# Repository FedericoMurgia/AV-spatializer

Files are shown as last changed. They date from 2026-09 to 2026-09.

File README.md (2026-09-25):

# AV Spatializer

**A five-control audiovisual controller by Studio Federico Murgia (beta)**

A joystick, a potentiometer and two sliders, with an 8×8 WS2812B LED matrix
under a frosted diffuser that shows what the controls are doing as light:
position, block size, brightness, colour and strobe. Built on an ESP32, in a
3D-printed enclosure.

<div align="center">

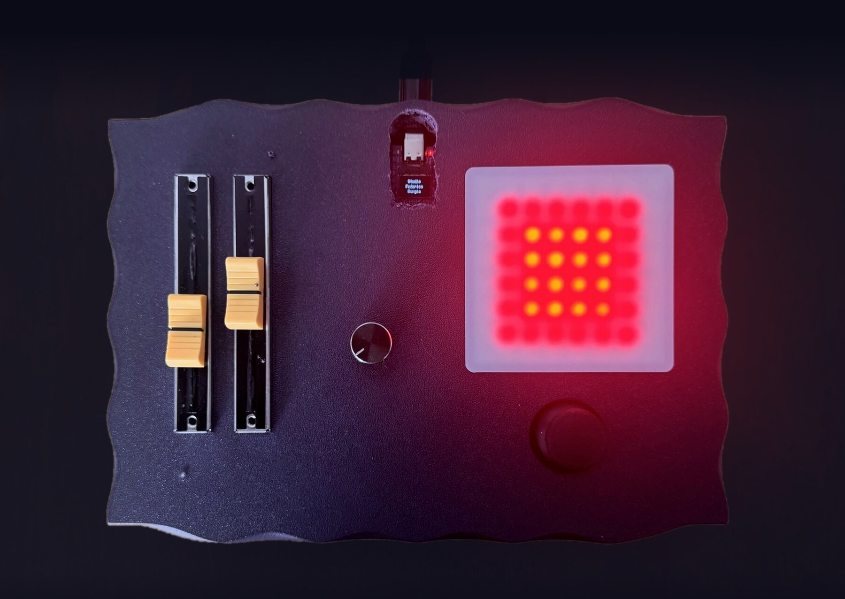
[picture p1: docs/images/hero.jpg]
AV Spatializer, top view


</div>

---

> [!WARNING]
> **Photosensitive epilepsy.** Two of the eight colour modes strobe the matrix
> at 1–20 Hz. Do not build or operate it if you are sensitive to
> photosensitive epilepsy.

> [!NOTE]
> **This is the beta.** It works, and it will change before a small limited
> edition. Two firmware variants exist and they
> do not do the same thing yet; see [Firmware](#firmware).

## What this is

The controller was first built as a spatializer: the joystick moves a sound
source around the room in 4DSOUND, a slider sets its size, and the LED matrix
mirrors where the source sits and how large it is.

<table>
<tr>
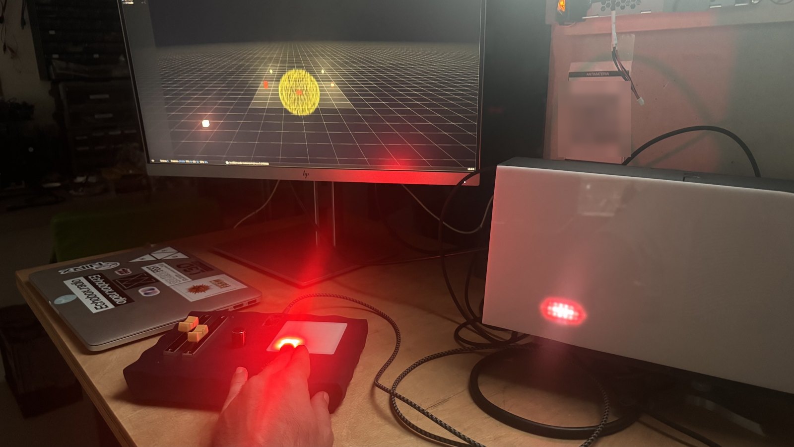
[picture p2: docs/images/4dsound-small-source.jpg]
Source made smaller and moved to the bottom left in 4DSOUND
<td width="50%"></td>
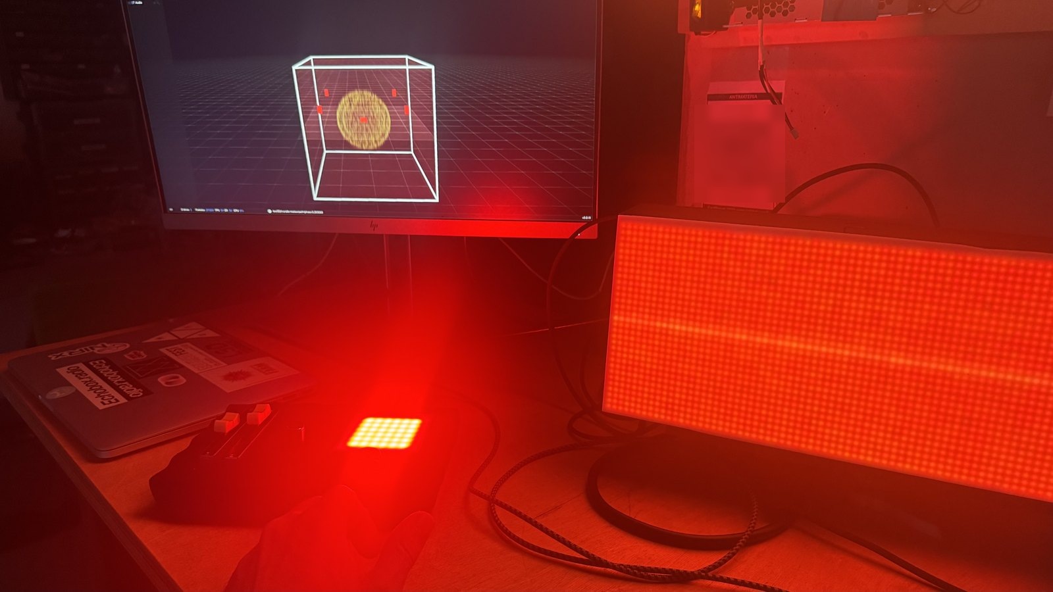
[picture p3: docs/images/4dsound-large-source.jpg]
The same source enlarged and left in the centre
<td width="50%"></td>
</tr>
<tr>
<td align="center"><em>The source made smaller and moved to the bottom left.</em></td>
<td align="center"><em>The same source enlarged and left in the centre.</em></td>
</tr>
</table>

It was then configured and performed for **Hotaru Open** with John Bringwolves
at Castello di Rivoli (May 2026, ADRenaline programme), where the joystick
positioned an audiovisual effect across a 10.1 speaker system and 16 lights.

<div align="center">
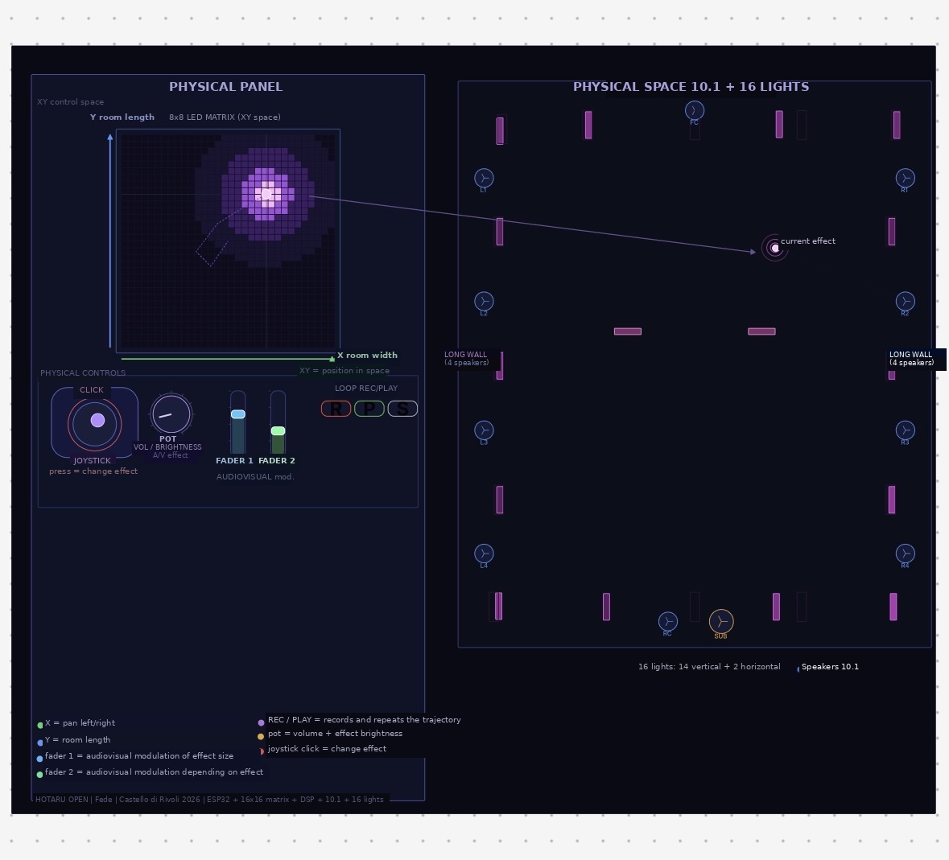
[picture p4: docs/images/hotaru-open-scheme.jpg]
Control scheme built for Hotaru Open


<em>The control scheme built and performed for Hotaru Open.</em>
</div>

Outside that setup it is a general-purpose controller: five continuous values
and a mode switch, readable by anything that takes MIDI or serial.

## Specifications

| | |
|---|---|
| **Controls** | 2-axis analog joystick with push, 1 rotary potentiometer, 2 slide potentiometers |
| **Display** | 8×8 WS2812B matrix (64 px) under a frosted diffuser |
| **Beta unit (pictured)** | ESP32-C3 board with onboard 0.42" 72×40 SSD1306 OLED, USB serial output |
| **BLE MIDI variant** | Classic ESP32, no screen, BLE MIDI Control Change output |
| **Frame rate** | 50 fps matrix update |
| **Enclosure** | 3D printed, two parts: top 217 × 157 × 26 mm, bottom 200 × 140 × 13.3 mm |

## Contents

| Path | What |
|---|---|
| [`docs/WIRING.md`](docs/WIRING.md) | Pin tables for both boards, matrix layout, power notes |
| [`docs/SERIAL.md`](docs/SERIAL.md) | The tagged serial stream from the ESP32-C3 firmware |
| [`docs/MIDI.md`](docs/MIDI.md) | The BLE MIDI map from the ESP32 firmware |
| [`docs/AV_Spatializer.pdf`](docs/AV_Spatializer.pdf) | Two-page overview sheet |
| [`firmware/`](firmware/) | Both firmware variants as PlatformIO projects |
| [`examples/`](examples/) | A minimal Python reader for the serial stream |
| [`hardware/enclosure/`](hardware/enclosure/) | Printable enclosure STLs |

## Controls

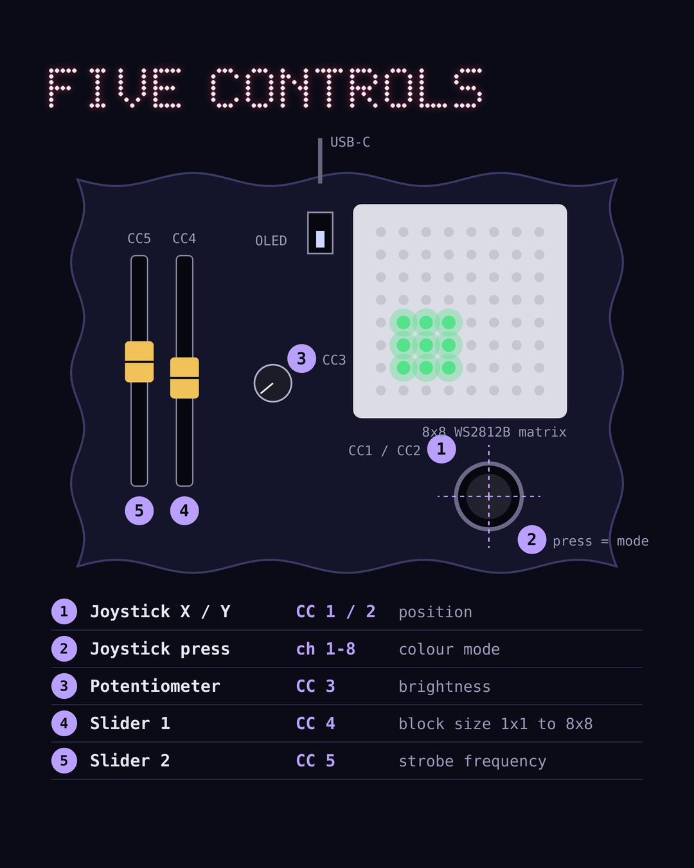
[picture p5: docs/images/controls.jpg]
The five controls


| # | Control | On the matrix | BLE MIDI variant |
|:-:|---|---|---|
| 1 | Joystick X / Y | Position of the lit block | CC 1 / CC 2 |
| 2 | Joystick press | Next colour mode (8 modes) | Channel = mode (1–7) |
| 3 | Potentiometer | Brightness | CC 3 |
| 4 | Slider 1 | Block size, 1×1 to 8×8 | CC 4 |
| 5 | Slider 2 | Strobe frequency, 1–20 Hz | CC 5 |

Odd block sizes above 1 are drawn as the next even size with a dimmed outer
ring (about 20% brightness).

The joystick centre is **calibrated at power-up** from 32 samples. Leave the
joystick untouched while the unit boots, or the centre will be offset for the
whole session.

### Colour modes

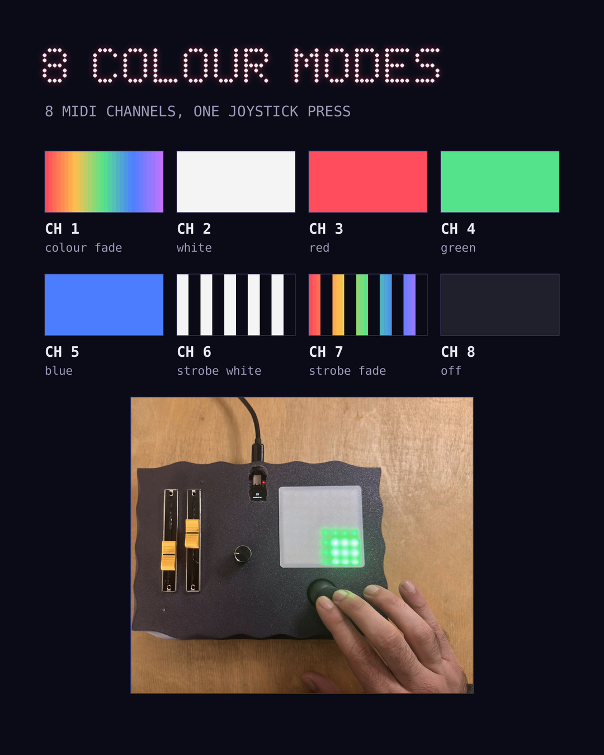
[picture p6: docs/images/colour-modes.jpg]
Eight colour modes


| Mode | Colour | MIDI channel (BLE variant) |
|:----:|---|:---:|
| 0 | Colour fade (hue cycles every frame) | 1 |
| 1 | White | 2 |
| 2 | Red | 3 |
| 3 | Green | 4 |
| 4 | Blue | 5 |
| 5 | Strobe white | 6 |
| 6 | Strobe fade | 7 |
| 7 | Off, matrix dark, no output | none |

## Build

### Bill of materials

| # | Component | Spec / Notes | Qty |
|---|---|---|:---:|
| 1 | Microcontroller | ESP32-C3 board with onboard 0.42" 72×40 SSD1306 OLED (C3 beta), **or** classic ESP32 dev board (BLE MIDI variant) | 1 |
| 2 | LED matrix | WS2812B 8×8 panel (64 LEDs) | 1 |
| 3 | OLED display | C3 beta only, onboard on the board above. The BLE MIDI variant has no screen | (1) |
| 4 | Analog joystick | KY-023 or equivalent (X/Y + button) | 1 |
| 5 | Potentiometer | 10 kΩ, panel-mount rotary | 1 |
| 6 | Slider potentiometer | 10 kΩ linear, panel-mount | 2 |
| 7 | Resistor | 330–470 Ω (WS2812 data line) | 1 |
| 8 | Capacitor | 100–1000 µF / 6.3 V (power decoupling on LED matrix VCC) | 1 |
| 9 | USB cable | Matching the board's USB connector | 1 |
| 10 | Enclosure | 3D printed, STLs in [`hardware/enclosure/`](hardware/enclosure/) | 1 |
| 11 | Wiring | 22–26 AWG hookup wire, various | — |
| 12 | PCB or perfboard | For mounting and connecting components | 1 |
| 13 | Diffuser | Frosted / opal acrylic over the matrix | 1 |

### Wiring

Pin tables for both boards: **[`docs/WIRING.md`](docs/WIRING.md)**.

### Enclosure

Two printed parts in [`hardware/enclosure/`](hardware/enclosure/).

<table>
<tr>
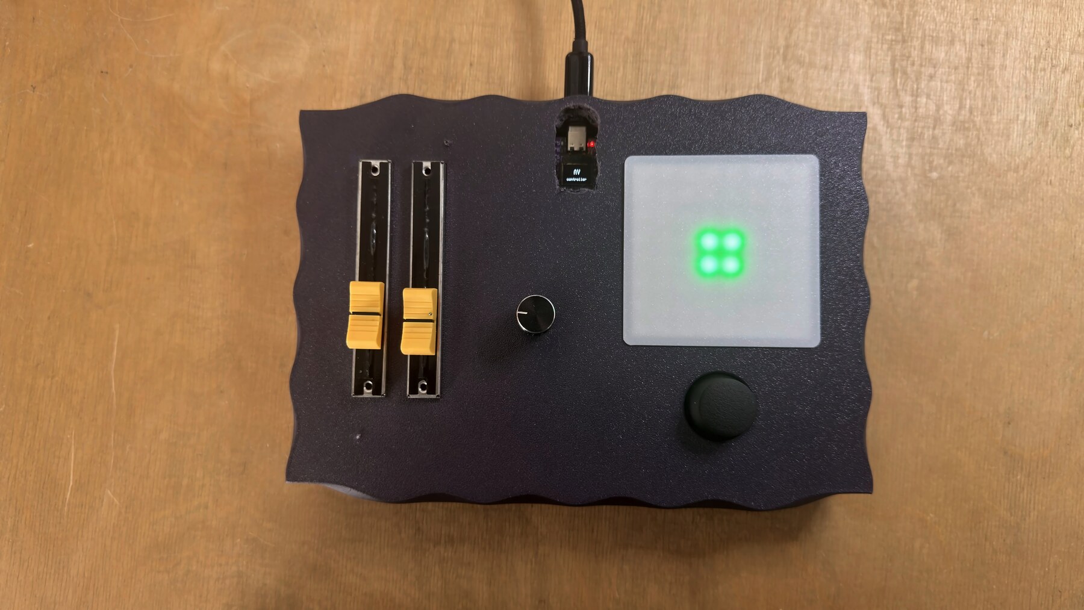
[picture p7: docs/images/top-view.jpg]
Top view in daylight
<td width="50%"></td>
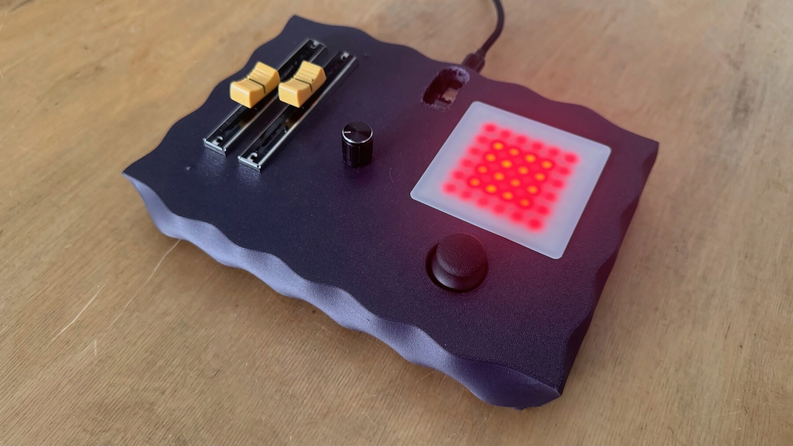
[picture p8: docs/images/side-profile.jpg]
Side profile of the enclosure
<td width="50%"></td>
</tr>
</table>

## Firmware

Two PlatformIO projects in [`firmware/`](firmware/). They share the same
control logic (joystick calibration, block drawing, colour modes, strobe) and
differ in output:

| | [`esp32c3-oled`](firmware/esp32c3-oled/) | [`esp32-blemidi`](firmware/esp32-blemidi/) |
|---|---|---|
| Board | ESP32-C3 with 0.42" OLED (the pictured beta) | Classic ESP32 |
| Output | USB serial, tagged stream, 50 Hz | BLE MIDI CC, ≤10 Hz per change |
| Screen | Shows brightness, size, strobe Hz, X/Y | None |
| Brightness | Pot sets 0–255 directly | Pot scaled per mode and block size, FastLED power cap |

**BLE MIDI is not yet in the ESP32-C3 firmware.** The C3 has Bluetooth LE, so
merging the two is the next step for the beta.

## Using it

<table>
<tr>
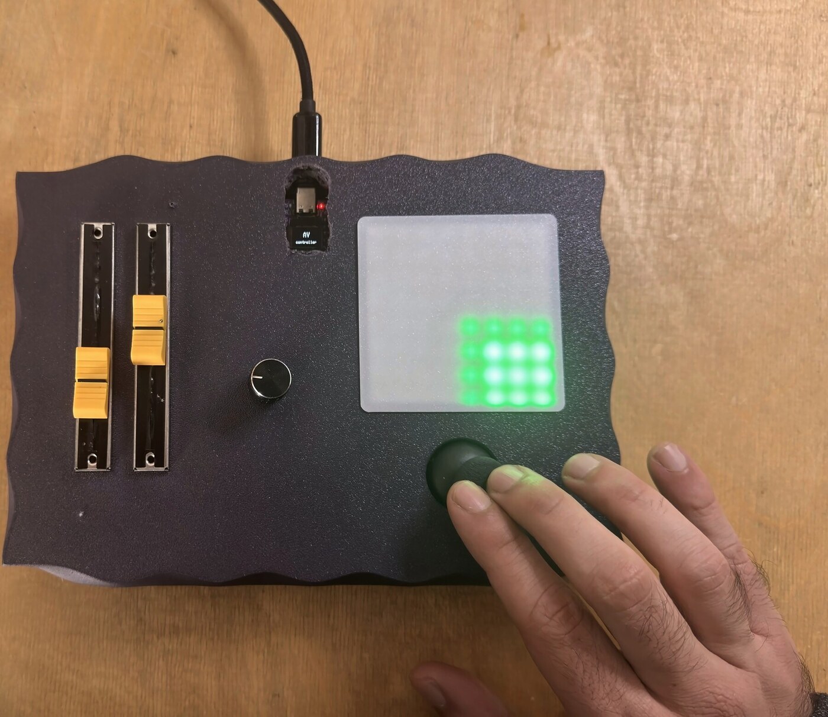
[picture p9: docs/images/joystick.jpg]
Joystick moving the lit block
<td width="50%"></td>
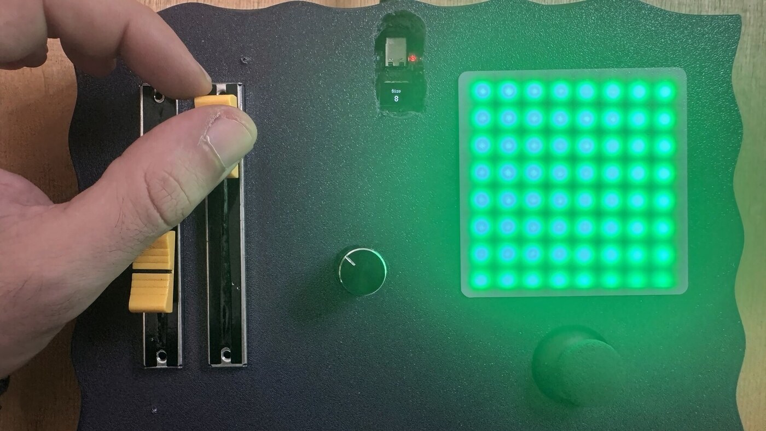
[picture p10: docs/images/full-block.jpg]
Block at full 8x8 size
<td width="50%"></td>
</tr>
<tr>
<td align="center"><em>Joystick moving the block.</em></td>
<td align="center"><em>Block at full 8×8 size.</em></td>
</tr>
</table>

- **BLE MIDI variant:** pair "AV Controller" as a Bluetooth MIDI device
  (macOS: Audio MIDI Setup → MIDI Studio → Bluetooth), then MIDI-learn the five
  CCs in Ableton Live, TouchDesigner, Max, Pure Data or any MIDI host.
- **ESP32-C3 beta:** open the USB serial port at 115200 baud and parse the
  stream; [`docs/SERIAL.md`](docs/SERIAL.md) has the format and
  [`examples/serial_reader.py`](examples/serial_reader.py) a working reader.

## Try one

Build your own from this repo, or get in touch: depending on the project, a beta
unit can be lent or sold at a small price. Whatever you find while building,
testing or breaking it, open an issue; the feedback goes into the limited
edition.

## License

- **Firmware and example code:** MIT, see [`LICENSE`](LICENSE)
- **Documentation, images and enclosure design:** CC BY-SA 4.0

## Credits

Built on [FastLED](https://github.com/FastLED/FastLED),
[U8g2](https://github.com/olikraus/u8g2) and
[NimBLE-Arduino](https://github.com/h2zero/NimBLE-Arduino).

AV Spatializer is a project by **Studio Federico Murgia**.

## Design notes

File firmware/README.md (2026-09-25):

# Firmware

Two PlatformIO projects. Open either folder in VS Code with the PlatformIO
extension, or build from the command line:

```sh
cd firmware/esp32c3-oled      # or firmware/esp32-blemidi
pio run -t upload
pio device monitor            # 115200 baud
```

| Folder | Board | Output | Libraries |
|---|---|---|---|
| [`esp32c3-oled/`](esp32c3-oled/) | ESP32-C3 with onboard 0.42" 72×40 SSD1306 | USB serial, see [`../docs/SERIAL.md`](../docs/SERIAL.md) | FastLED, U8g2 |
| [`esp32-blemidi/`](esp32-blemidi/) | Classic ESP32 | BLE MIDI, see [`../docs/MIDI.md`](../docs/MIDI.md) | FastLED, NimBLE-Arduino 1.x |

The `platformio.ini` files are reference configs. The C3 build enables USB CDC
on boot so `Serial` appears on the native USB port; if your C3 board has a
separate USB-UART chip, remove those two flags.

## Settings worth knowing

All at the top of each `main.cpp`:

| Constant | Value | Effect |
|---|---|---|
| `DEADZONE` | 250 | ADC counts around the joystick centre that read as centre |
| `AXIS_HALF_RANGE` | 1500 | Joystick travel mapped to the full grid, kept under the ADC limit so full deflection reaches the edge |
| `STROBE_HZ_MIN` / `MAX` | 1 / 20 | Strobe range on slider 2 |
| `FRAME_INTERVAL_MS` | 20 | 50 fps |
| `DEBOUNCE_MS` | 50 | Joystick push debounce |

## Roadmap

- Bring BLE MIDI into the ESP32-C3 firmware, so the pictured unit sends MIDI
  and keeps its screen.

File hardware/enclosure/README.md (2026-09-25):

# Enclosure

Two 3D-printed parts. Sizes are the STL bounding boxes.

| File | Bounding size | Role |
|---|---|---|
| `av-spatializer-top.stl` | 217 × 157 × 26 mm | Top shell (was `AVmidicontroller.stl`) |
| `av-spatializer-bottom.stl` | 200 × 140 × 13.3 mm | Bottom (was `AVcontrollerbottom.stl`) |

The diffuser over the LED matrix is not printed: use frosted or opal acrylic
cut to the matrix window.

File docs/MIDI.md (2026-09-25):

# BLE MIDI (ESP32 firmware)

The `esp32-blemidi` firmware advertises as **"AV Controller"** using the
standard BLE MIDI service (`03B80E5A-EDE8-4B33-A751-6CE34EC4C700`). Pair it as a
Bluetooth MIDI device on the host; on macOS through Audio MIDI Setup → MIDI
Studio → Bluetooth.

## Map

| Control | CC | Value |
|---|:--:|---|
| Joystick X | 1 | Grid position 0–8 scaled to 0–127 |
| Joystick Y | 2 | Grid position 0–8 scaled to 0–127 |
| Potentiometer | 3 | 0–127 |
| Slider 1 | 4 | 0–127 (inverted in firmware to match block size) |
| Slider 2 | 5 | 0–127 (inverted in firmware to match strobe rate) |

**Channel = colour mode + 1.** A joystick press moves to the next mode, and all
five CCs move to the next channel with it. On a channel change all five CCs are
sent at once, so the host receives the current state on the new channel.

## Timing

- CCs are checked every **100 ms** and only sent when they change: X and Y on
  any change, the potentiometer and sliders when they move by more than 1.
- Each CC is sent as its own BLE notification, the most widely compatible form.
- Joystick X/Y are quantised to the 9 grid positions, so they step
  (0, 15, 31, 47 … 127) rather than sweep.

## Known behaviour

- **Mode 7 is off:** the matrix goes dark and no MIDI is sent. Channels 1–7
  carry the CCs.
- Joystick centre is calibrated at power-up. Do not touch the joystick while
  the board boots.

## Library

Written against **NimBLE-Arduino 1.x**. Version 2.x changed the server callback
signatures (`onConnect`, `onDisconnect`), so the callbacks here will not compile
against 2.x without updating them. `platformio.ini` pins 1.x.

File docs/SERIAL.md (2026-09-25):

# Serial stream (ESP32-C3 firmware)

USB serial, **115200 baud**. After boot the board prints `ready`, then one line
per frame (50 Hz):

```
sx-2051-sy-2040-x-4-y-4-p-3120-s1-812-s2-3990-m-0
```

| Tag | Value | Range |
|-----|---|---|
| `sx` | Joystick X, smoothed raw ADC | 0–4095 |
| `sy` | Joystick Y, smoothed raw ADC | 0–4095 |
| `x` | Joystick X as grid position | 0–8, 4 = centre |
| `y` | Joystick Y as grid position | 0–8, 4 = centre |
| `p` | Potentiometer, smoothed raw ADC | 0–4095 |
| `s1` | Slider 1, smoothed raw ADC | 0–4095 |
| `s2` | Slider 2, smoothed raw ADC | 0–4095 |
| `m` | Colour mode | 0–7 |

Notes read from the firmware:

- `sx`/`sy` are exponentially smoothed (α 0.4); `p`, `s1`, `s2` use α 0.8.
- `x`/`y` include a dead zone of ±250 ADC counts around the centre calibrated
  at boot, so small movements report 4.
- `s1` and `s2` are raw. The firmware inverts them internally: block size is
  `map(s1, 0, 4095, 8, 1)` and strobe is `1 + (4095 - s2) / 4095 × 19` Hz.
- In mode 7 (off) the matrix is blanked and **no lines are sent** until the
  mode changes.

A minimal reader is in [`../examples/serial_reader.py`](../examples/serial_reader.py).

## OLED

The onboard 72×40 screen shows whichever control moved last:

| Moved | Screen |
|---|---|
| Potentiometer | `Bright` and 0–100 % |
| Slider 1 | `Size` and 1–8 |
| Slider 2 | `Strobe` and Hz |
| Joystick | `X  Y` and offset from centre, −4 to +4 |

In the two strobe modes it shows `STROBE` once and then stops redrawing. After
two seconds without activity it alternates between two idle pages.

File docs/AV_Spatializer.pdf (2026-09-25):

ESP32-C3 audiovisual MIDI controller, five controls, 8x8 LED matrix | BETA

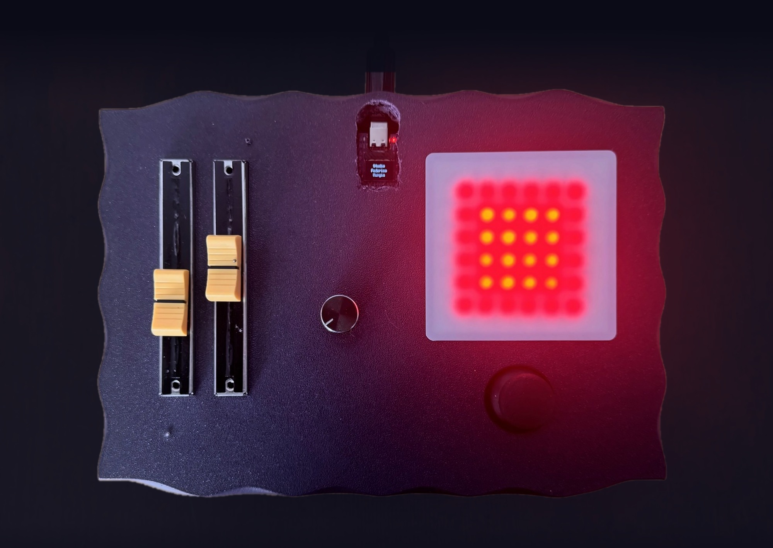
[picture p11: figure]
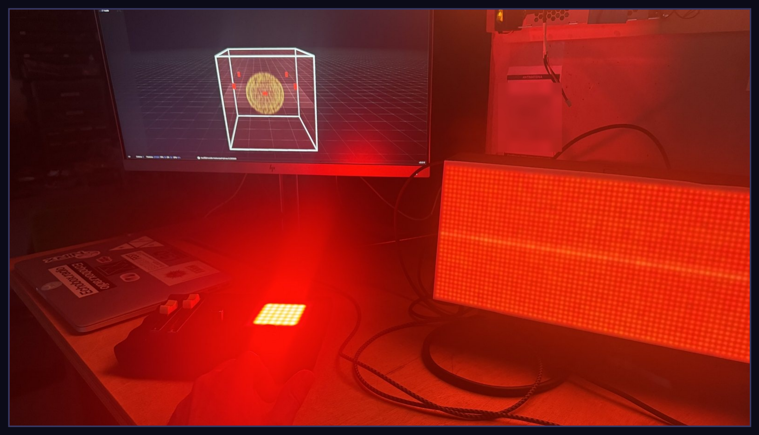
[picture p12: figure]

Studio Federico Murgia, Amsterdam | 1 / 2

Top view: sliders, potentiometer, 8x8 LED matrix under a frosted diffuser, joystick, OLED display and USB-C.

WHAT IT IS
A hand-built controller with five controls: a two-axis joystick with click, a potentiometer and two sliders. An 8x8 WS2812B LED matrix under a frosted diffuser shows what the controls are doing as light: position, block size, brightness, colour and strobe are read directly on the panel while playing.

It runs on an ESP32-C3 and sends five Control Change messages over BLE MIDI, or a tagged serial stream over USB, so it can be mapped in any MIDI-capable host: Ableton Live, TouchDesigner, Max, Pure Data, lighting software and spatial audio systems. One gesture drives sound and light together.

BORN AS A SPATIALIZER
The controller was first built to move and scale a sound source in 4DSOUND. The joystick places the source in the room, a slider sets its size, and the LED matrix mirrors where the source sits and how large it is.

Moving and scaling a sound source in 4DSOUND, own studio: the source made smaller and moved to the bottom left.

The same source enlarged and left in the centre.

Control scheme built and performed for Hotaru Open.

HOTARU OPEN, CASTELLO DI RIVOLI, MAY 2026
It was then configured and performed for Hotaru Open, a residency and public event with John Bringwolves at Castello di Rivoli within the ADRenaline programme, where 15 students from Turin institutions performed spatialised audiovisual compositions with custom-built instruments and interfaces.

There it drove a 10.1 speaker system and 16 lights (14 vertical, 2 horizontal). The joystick positioned an audiovisual effect in the room, heard and seen in the same place. The click changed effect, the potentiometer set volume and effect brightness together, and the two sliders modulated the effect audiovisually. Joystick trajectories could be recorded and looped in the patch.

MIDI map, onboard behaviour, the Hotaru Open mapping and general-purpose use

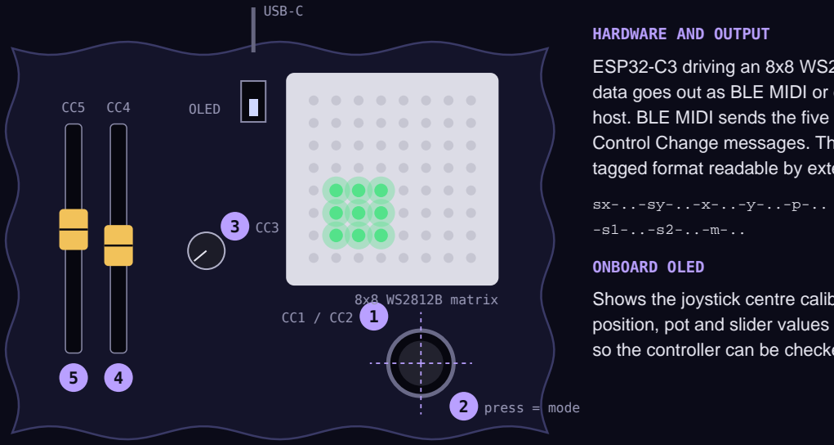
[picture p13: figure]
2 press = mode; OLED; USB-C; 8x8 WS2812B matrix; HARDWARE AND OUTPUT; ONBOARD OLED
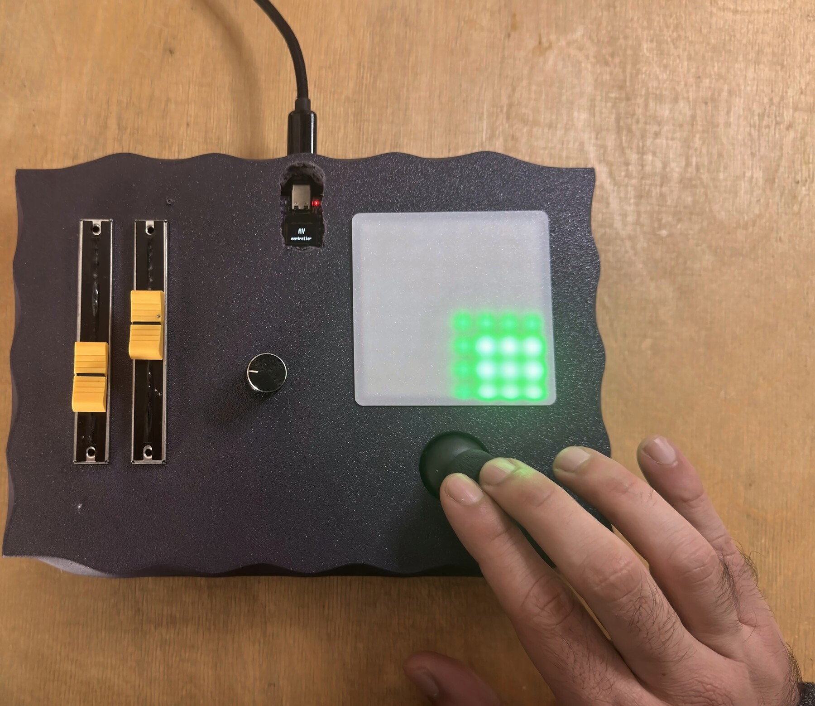
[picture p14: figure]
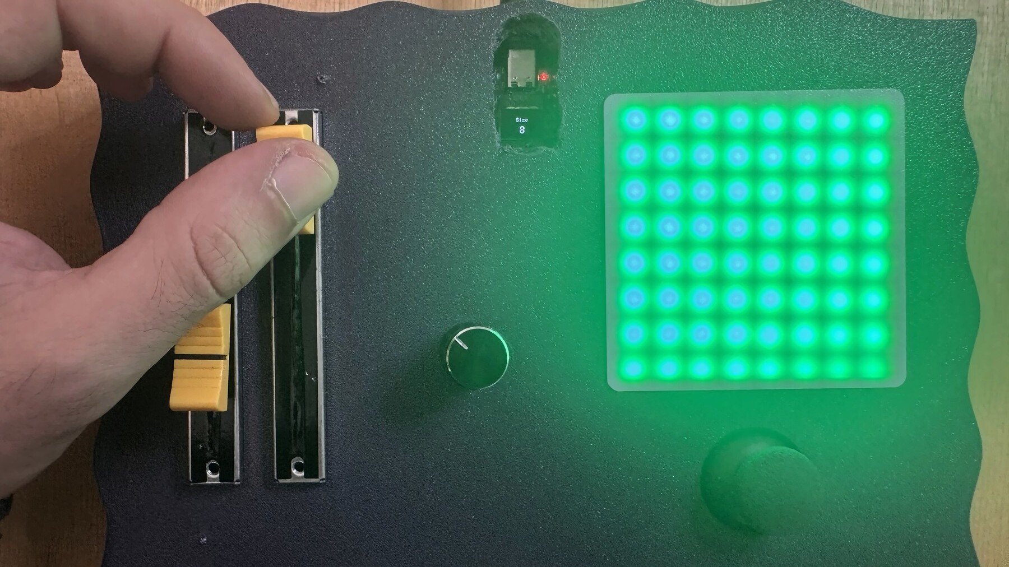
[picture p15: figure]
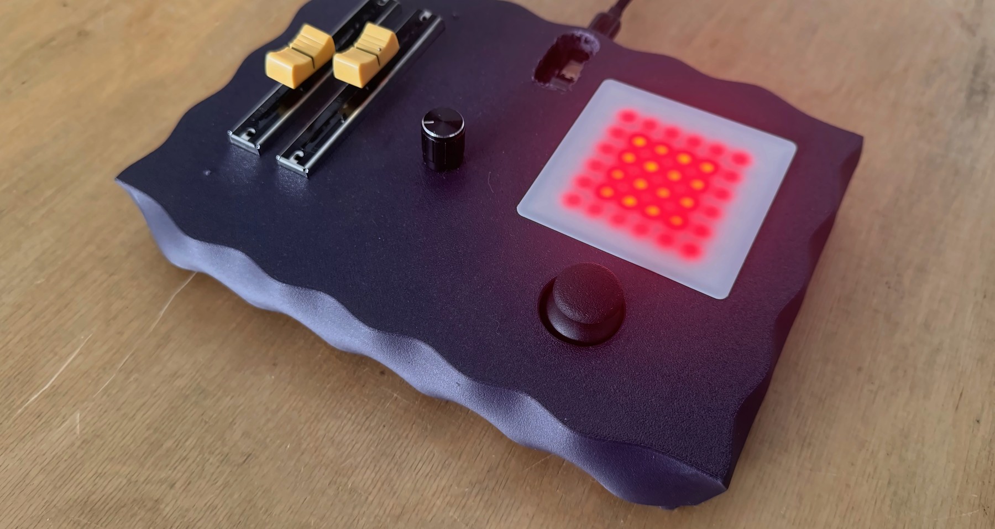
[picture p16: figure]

Studio Federico Murgia, Amsterdam | 2 / 2

EIGHT COLOUR MODES, EIGHT MIDI CHANNELS

CH 1
colour
fade

CH 2
white

CH 3
red

CH 4
green

CH 5
blue

CH 6
strobe
white

CH 7
strobe
fade

CH 8
off

A joystick press steps to the next mode. Each mode sends on its own MIDI channel, so switching mode switches channel and all five CCs follow: one controller addresses eight separate layers in the host.

ESP32-C3 driving an 8x8 WS2812B LED matrix. Control data goes out as BLE MIDI or over serial, depending on the host. BLE MIDI sends the five parameters as standard Control Change messages. The serial stream uses a tagged format readable by external parsers:

Shows the joystick centre calibration offsets, the X/Y grid position, pot and slider values and the active colour mode, so the controller can be checked without a computer.

CONTROL | ON THE PANEL | HOTARU OPEN | GENERAL PURPOSE

### 1 Joystick X / Y

CC 1 / CC 2, 0-127

Horizontal and vertical position of the lit block on the matrix.

X = pan left / right, Y = room length: position of the effect in the room.

Any pair of parameters as an XY pad: source position, filter cutoff and resonance, position of a light or visual element.

### 2 Joystick press

8 modes = ch 1-8

Steps through the eight colour modes.

| | Change effect. | Layer, scene or instrument select: all
CCs move to the new channel.
3 Potentiometer CC 3, 0-127 | LED brightness. | Volume and effect brightness
together.

Master level coupling loudness and light intensity, or any continuous parameter.

4 Slider 1 CC 4, 0-127 | Block size, from 1x1 to 8x8. | Audiovisual modulation of
effect size.

Size or spread of a source, send amount, scale or blur of a visual.

5 Slider 2 CC 5, 0-127 | Strobe frequency. | Audiovisual modulation
depending on the effect.

Rate parameters: LFO speed, tremolo, strobe or flicker of fixtures.

Joystick moving the block. | Block at full 8x8 size. | Side profile of the enclosure.

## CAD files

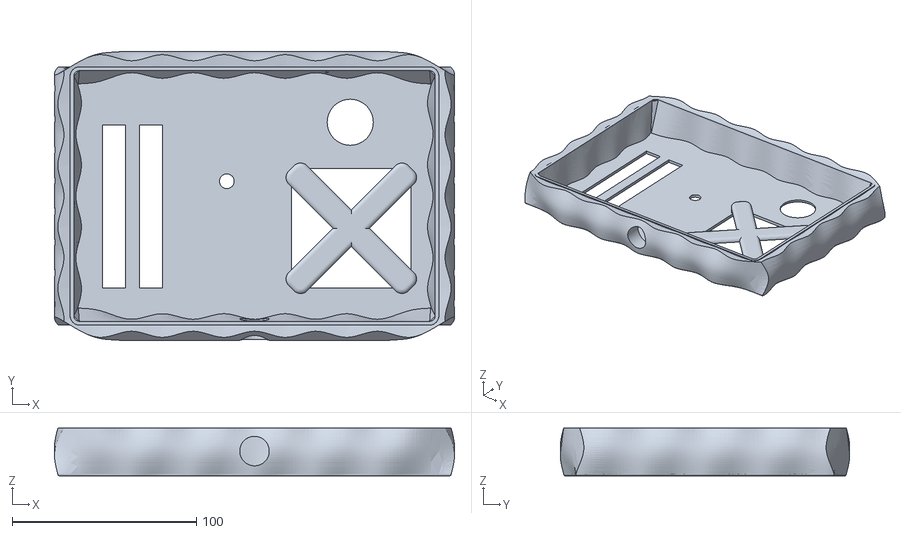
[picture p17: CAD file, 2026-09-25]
hardware/enclosure/av-spatializer-top.stl
217.0 x 157.0 x 26.0

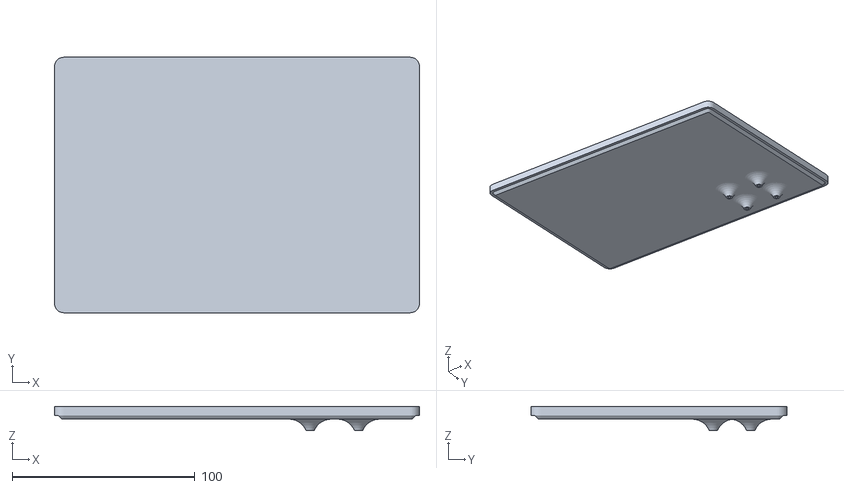
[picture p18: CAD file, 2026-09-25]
hardware/enclosure/av-spatializer-bottom.stl
200.0 x 140.0 x 13.3

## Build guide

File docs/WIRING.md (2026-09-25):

# Wiring

Pins are set as constants at the top of each `main.cpp`. Match the wiring to
them, or change the constants and rebuild.

## ESP32-C3 beta (`firmware/esp32c3-oled`)

| Function | GPIO | Notes |
|---|:----:|---|
| WS2812B data | 7 | |
| Joystick X | 0 | ADC1 |
| Joystick Y | 1 | ADC1 |
| Joystick push | 8 | `INPUT_PULLUP`, switch to GND |
| Potentiometer | 2 | ADC1 |
| Slider 1 | 3 | ADC1 |
| Slider 2 | 4 | ADC1 |
| OLED SDA | 5 | Onboard 0.42" 72×40 SSD1306 |
| OLED SCL | 6 | Onboard |

All five analog inputs are on ADC1, read at 12 bit with 11 dB attenuation
(0–4095 over roughly the full 3.3 V swing).

## ESP32 BLE MIDI variant (`firmware/esp32-blemidi`)

| Function | GPIO | Notes |
|---|:----:|---|
| WS2812B data | 0 | |
| Joystick X | 34 | ADC1, input-only pin |
| Joystick Y | 35 | ADC1, input-only pin |
| Joystick push | 25 | `INPUT_PULLUP`, switch to GND |
| Potentiometer | 27 | ADC2 |
| Slider 1 | 26 | ADC2 |
| Slider 2 | 33 | ADC1 |

The firmware does a discarded read and a 100 µs settle after every ADC channel
switch before averaging four samples.

ADC2 (GPIO 25–27) cannot be read while Wi-Fi is active on the classic ESP32.
This firmware uses Bluetooth only, so it is fine as is; keep it in mind before
adding Wi-Fi.

## Potentiometers and joystick

Wire each potentiometer and each joystick axis as a voltage divider between
3V3 and GND, wiper to the GPIO. Slider direction is handled in firmware: at the
low-ADC end slider 1 gives the largest block and slider 2 the highest strobe
rate. If yours runs the other way, swap the outer legs.

## Matrix layout

`xyToIndex()` assumes **non-serpentine** wiring: every row runs right to left,
row 0 first. A serpentine matrix will show every other row mirrored; change
`xyToIndex()` rather than rewiring.

## Power

The unit runs from USB. Current at the matrix is the thing to watch:

- **ESP32-C3 firmware:** the potentiometer maps straight to FastLED brightness
  0–255 and there is no current cap. A full 8×8 white block at maximum
  brightness can ask for far more than a USB port or the board's regulator
  supplies. Keep brightness moderate, or add
  `FastLED.setMaxPowerInVoltsAndMilliamps()` as in the BLE variant.
- **BLE MIDI firmware:** brightness is scaled down per colour mode and block
  size, and FastLED is capped with `setMaxPowerInVoltsAndMilliamps(5, 50)`,
  which leaves headroom for BLE radio bursts.

Tie all grounds together.

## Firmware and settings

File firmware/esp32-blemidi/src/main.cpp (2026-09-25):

#include <Arduino.h>
#include <FastLED.h>
#include <NimBLEDevice.h>

// ── BLE MIDI ──────────────────────────────────────────────────────────────────
// BLE MIDI service/characteristic UUIDs (spec-defined).
#define BLEMIDI_SERVICE_UUID        "03B80E5A-EDE8-4B33-A751-6CE34EC4C700"
#define BLEMIDI_CHAR_UUID           "7772E5DB-3868-4112-A1A9-F2669D106BF3"

static NimBLECharacteristic* bleMidiChar = nullptr;
static bool                  bleConnected = false;

class MidiServerCB : public NimBLEServerCallbacks {
  void onConnect(NimBLEServer*)    override { bleConnected = true; }
  void onDisconnect(NimBLEServer*) override {
    bleConnected = false;
    NimBLEDevice::getAdvertising()->start();
  }
};

// Send a single BLE MIDI CC message (one notify per CC — universally compatible).
static void bleMidiSendCC(uint8_t channel, uint8_t cc, uint8_t value) {
  if (!bleConnected || !bleMidiChar) return;
  const uint16_t t      = millis() & 0x1FFF;
  const uint8_t  header = 0x80 | ((t >> 7) & 0x3F);
  const uint8_t  ts     = 0x80 | (t & 0x7F);
  const uint8_t  status = 0xB0 | ((channel - 1) & 0x0F);
  const uint8_t  pkt[]  = { header, ts, status, cc, value };
  bleMidiChar->setValue(pkt, sizeof(pkt));
  bleMidiChar->notify();
}

static void bleMidiSendCCs(uint8_t channel,
                            uint8_t x, uint8_t y,
                            uint8_t p, uint8_t s1, uint8_t s2) {
  bleMidiSendCC(channel, 1, x);
  bleMidiSendCC(channel, 2, y);
  bleMidiSendCC(channel, 3, p);
  bleMidiSendCC(channel, 4, s1);
  bleMidiSendCC(channel, 5, s2);
}

static void bleMidiInit() {
  NimBLEDevice::init("AV Controller");
  NimBLEDevice::setPower(ESP_PWR_LVL_P9);  // max TX power

  NimBLEServer* srv = NimBLEDevice::createServer();
  srv->setCallbacks(new MidiServerCB());

  NimBLEService* svc = srv->createService(BLEMIDI_SERVICE_UUID);
  bleMidiChar = svc->createCharacteristic(
    BLEMIDI_CHAR_UUID,
    NIMBLE_PROPERTY::READ | NIMBLE_PROPERTY::WRITE_NR | NIMBLE_PROPERTY::NOTIFY
  );
  svc->start();

  NimBLEAdvertising* adv = NimBLEDevice::getAdvertising();
  adv->addServiceUUID(BLEMIDI_SERVICE_UUID);
  adv->setScanResponse(true);   // puts the 128-bit UUID in scan response (needed for iOS)
  adv->setMinInterval(0x20);    // 20ms — fast advertising for quick discovery
  adv->setMaxInterval(0x40);
  adv->start();

  Serial.println("BLE MIDI advertising as 'AV Controller'");
}
// ─────────────────────────────────────────────────────────────────────────────

namespace {

// Matrix size.
constexpr uint8_t  MATRIX_WIDTH  = 8;
constexpr uint8_t  MATRIX_HEIGHT = 8;
constexpr uint16_t LED_COUNT     = MATRIX_WIDTH * MATRIX_HEIGHT;

// Pins.
constexpr uint8_t LED_PIN              = 0;
constexpr uint8_t JOYSTICK_X_PIN       = 34;
constexpr uint8_t JOYSTICK_Y_PIN       = 35;
constexpr uint8_t JOYSTICK_BUTTON_PIN  = 25;
constexpr uint8_t POT_PIN              = 27;
constexpr uint8_t SLIDER1_PIN          = 26;
constexpr uint8_t SLIDER2_PIN          = 33;

// LED brightness.
constexpr uint8_t BRIGHTNESS = 40;

// Target ~50 fps.
constexpr uint32_t FRAME_INTERVAL_MS = 20;

// Ignore tiny joystick movement around the center.
constexpr int DEADZONE = 250;

// Minimum stable time before a button press is accepted.
constexpr uint32_t DEBOUNCE_MS = 50;

// Full 12-bit ADC range.
constexpr int ADC_MAX = 4095;

// Symmetric deflection range around center — set at boot from the calibrated
// center so both directions feel identical from the first frame.
constexpr int AXIS_HALF_RANGE = 1500;

CRGB leds[LED_COUNT];

// Calibrated center values.
int centerX = 2048;
int centerY = 2048;

// Observed ADC extremes — set symmetrically from center in calibrateJoystick().
int axisMinX = 0, axisMaxX = ADC_MAX;
int axisMinY = 0, axisMaxY = ADC_MAX;

// Exponential moving average state — smooths ADC noise between frames.
// Higher alpha = faster response but less smoothing.
constexpr float EMA_ALPHA        = 0.4f;
constexpr float EMA_ALPHA_ANALOG = 0.3f;
float emaX   = 2048.0f;
float emaY   = 2048.0f;
float emaPot = 2048.0f;
float emaSl1 = 2048.0f;
float emaSl2 = 2048.0f;

// Button debounce state.
bool lastButtonReading = HIGH;
bool stableButtonState = HIGH;
uint32_t lastDebounceTime = 0;

// Colour cycle:
//   0=fade(1px)  1=white(2×2)  2=red(2×2)  3=green(2×2)  4=blue(2×2)
//   5=strobe white(2×2)  6=strobe fade(2×2)  7=off
uint8_t colorMode = 0;
constexpr uint8_t COLOR_MODES = 8;

// Strobe: 15 Hz → period ~67 ms, on for first half.
// Strobe frequency range controlled by s2 slider.
constexpr float STROBE_HZ_MIN = 1.0f;
constexpr float STROBE_HZ_MAX = 20.0f;

// Hue for fading mode — incremented every frame (~5 s per full cycle at 50 fps).
uint8_t fadeHue = 0;

// Track whether display was active last frame to know when to blank.
bool displayWasEnabled = true;

// Convert matrix coordinates to LED index.
// All rows go right-to-left (non-serpentine wiring).
uint16_t xyToIndex(uint8_t x, uint8_t y) {
  return static_cast<uint16_t>(y * MATRIX_WIDTH + (MATRIX_WIDTH - 1 - x));
}

// Average several ADC readings at startup to find the true resting center.
void calibrateJoystick() {
  delay(250);

  long sumX = 0;
  long sumY = 0;
  constexpr uint8_t SAMPLES = 32;

  for (uint8_t i = 0; i < SAMPLES; i++) {
    sumX += analogRead(JOYSTICK_X_PIN);
    sumY += analogRead(JOYSTICK_Y_PIN);
    delay(2);
  }

  centerX = static_cast<int>(sumX / SAMPLES);
  centerY = static_cast<int>(sumY / SAMPLES);

  axisMinX = centerX - AXIS_HALF_RANGE;
  axisMaxX = centerX + AXIS_HALF_RANGE;
  axisMinY = centerY - AXIS_HALF_RANGE;
  axisMaxY = centerY + AXIS_HALF_RANGE;

  emaX = static_cast<float>(centerX);
  emaY = static_cast<float>(centerY);
}

// Average several ADC reads and clamp to the safe window to avoid
// ESP32 saturation crosstalk near the ADC rails.
// A dummy read + settling delay is required after channel switches.
int smoothAnalogRead(uint8_t pin, uint8_t samples = 4) {
  analogRead(pin);           // discard — lets the ADC mux settle after channel switch
  delayMicroseconds(100);
  long sum = 0;
  for (uint8_t i = 0; i < samples; i++) sum += analogRead(pin);
  return constrain(static_cast<int>(sum / samples), 0, ADC_MAX);
}

// Map a joystick axis to a matrix position [0, size-1].
// Each direction is mapped independently from the observed ADC extreme to the
// deadzone edge, so both sides always reach position 0 / size-1 regardless of
// how asymmetric the joystick's physical range is.
uint8_t joystickToPosition(int rawValue, int centerValue,
                           int axisMin, int axisMax, uint8_t size) {
  const int delta = rawValue - centerValue;

  if (abs(delta) < DEADZONE) return size / 2;

  long position;
  if (delta < 0) {
    position = map(rawValue, centerValue - DEADZONE, axisMin, size / 2 - 1, 0);
  } else {
    position = map(rawValue, centerValue + DEADZONE, axisMax, size / 2, size - 1);
  }
  return static_cast<uint8_t>(constrain(position, 0, size - 1));
}

// Cycle colour mode on each button press, with debounce.
void updateButton() {
  const bool reading = digitalRead(JOYSTICK_BUTTON_PIN);

  if (reading != lastButtonReading) {
    lastDebounceTime = millis();
  }
  lastButtonReading = reading;

  if ((millis() - lastDebounceTime) > DEBOUNCE_MS) {
    if (reading != stableButtonState) {
      stableButtonState = reading;
      if (stableButtonState == LOW) {
        colorMode = (colorMode + 1) % COLOR_MODES;
      }
    }
  }
}

// Draw the pixel(s) that track the joystick position.
void drawPixelFromJoystick() {
  // Mode 7 = off.
  if (colorMode == 7) {
    if (displayWasEnabled) {
      FastLED.clear(true);
      displayWasEnabled = false;
    }
    return;
  }
  displayWasEnabled = true;

  const int rawX = smoothAnalogRead(JOYSTICK_X_PIN);
  const int rawY = smoothAnalogRead(JOYSTICK_Y_PIN);

  // Apply EMA to further smooth inter-frame noise.
  emaX = EMA_ALPHA * rawX + (1.0f - EMA_ALPHA) * emaX;
  emaY = EMA_ALPHA * rawY + (1.0f - EMA_ALPHA) * emaY;
  const int sX  = static_cast<int>(emaX);
  const int sY  = static_cast<int>(emaY);
  emaPot = EMA_ALPHA_ANALOG * smoothAnalogRead(POT_PIN)     + (1.0f - EMA_ALPHA_ANALOG) * emaPot;
  emaSl1 = EMA_ALPHA_ANALOG * smoothAnalogRead(SLIDER1_PIN) + (1.0f - EMA_ALPHA_ANALOG) * emaSl1;
  emaSl2 = EMA_ALPHA_ANALOG * smoothAnalogRead(SLIDER2_PIN) + (1.0f - EMA_ALPHA_ANALOG) * emaSl2;
  const int pot = static_cast<int>(emaPot);
  const int sl1 = ADC_MAX - static_cast<int>(emaSl1);
  const int sl2 = ADC_MAX - static_cast<int>(emaSl2);



  FastLED.clear();

  // Block size from s1: 1×1 to 8×8.
  // Odd sizes > 1 display as the next even size with a dimmed outer ring.
  const int blockSize = 1 + (sl1 * 7 / 4095);
  const bool hasDimRing = (blockSize > 1 && blockSize % 2 == 1);
  const int displaySize = hasDimRing ? blockSize + 1 : blockSize;

  // Brightness: start from pot, then scale down by mode and block size.
  // Fade (0) and white (1) are brighter colours so need extra reduction.
  int brightness;
  if      (colorMode == 3 || colorMode == 4) brightness = map(pot, 0, 4095, 0, 70);
  else if (colorMode == 0 || colorMode == 1) brightness = map(pot, 0, 4095, 0, 22);
  else                                       brightness = map(pot, 0, 4095, 0, 45);
  if      (displaySize >= 7) brightness /= 4;   // 8px → 25%
  else if (displaySize >= 3) brightness /= 2;   // 4–6px → 50%
  FastLED.setBrightness(brightness);

  // Joystick maps to the top-left corner of the block so it can slide fully to each edge.
  const uint8_t sizeX = MATRIX_WIDTH  + displaySize - 1;
  const uint8_t sizeY = MATRIX_HEIGHT + displaySize - 1;
  const uint8_t xPos  = joystickToPosition(sX, centerX, axisMinX, axisMaxX, sizeX);
  const uint8_t yBot  = joystickToPosition(sY, centerY, axisMinY, axisMaxY, sizeY);
  const int bx = (int)xPos - (displaySize - 1);
  const int by = (int)(MATRIX_HEIGHT - yBot) - 1;

  // Strobe phase accumulator — runs in all modes so switching doesn't reset it.
  static float strobePhase = 0.0f;
  const float strobeHz = STROBE_HZ_MIN + (sl2 / 4095.0f) * (STROBE_HZ_MAX - STROBE_HZ_MIN);
  strobePhase += strobeHz * (FRAME_INTERVAL_MS / 1000.0f);
  if (strobePhase >= 1.0f) strobePhase -= 1.0f;
  const bool strobeOn = strobePhase < 0.5f;

  if (colorMode == 0) fadeHue++;
  if (colorMode == 6) fadeHue++;

  CRGB color;
  switch (colorMode) {
    case 0: color = CHSV(fadeHue, 255, 255);                         break;
    case 1: color = CRGB::White;                                      break;
    case 2: color = CRGB::Red;                                        break;
    case 3: color = CRGB::Green;                                      break;
    case 4: color = CRGB::Blue;                                       break;
    case 5: color = strobeOn ? CRGB::White : CRGB::Black;            break;
    case 6: color = strobeOn ? CRGB(CHSV(fadeHue, 255, 255))
                             : CRGB::Black;                           break;
    default: color = CRGB::Black;                                     break;
  }

  const uint8_t joyX = joystickToPosition(sX, centerX, axisMinX, axisMaxX, 9);
  const uint8_t joyY = joystickToPosition(sY, centerY, axisMinY, axisMaxY, 9);

  // BLE MIDI — send CCs on the channel matching the active mode (1-8).
  // Rate-limited to 20 Hz so BLE isn't overwhelmed.
  static uint32_t lastMidi = 0;
  static uint8_t  prevX = 255, prevY = 255, prevP = 255, prevS1 = 255, prevS2 = 255;
  static uint8_t  prevCh = 0;
  const uint32_t nowMidi = millis();
  if (nowMidi - lastMidi >= 100) {
    lastMidi = nowMidi;
    const uint8_t ch  = colorMode + 1;
    const uint8_t mx  = map(joyX, 0, 8,    0, 127);
    const uint8_t my  = map(joyY, 0, 8,    0, 127);
    const uint8_t mp  = map(pot,  0, 4095, 0, 127);
    const uint8_t ms1 = map(sl1,  0, 4095, 0, 127);
    const uint8_t ms2 = map(sl2,  0, 4095, 0, 127);
    const bool chChanged = (ch != prevCh);
    if (chChanged || mx  != prevX)  { bleMidiSendCC(ch, 1, mx);  prevX  = mx; }
    if (chChanged || my  != prevY)  { bleMidiSendCC(ch, 2, my);  prevY  = my; }
    if (chChanged || abs((int)mp  - (int)prevP)  > 1) { bleMidiSendCC(ch, 3, mp);  prevP  = mp; }
    if (chChanged || abs((int)ms1 - (int)prevS1) > 1) { bleMidiSendCC(ch, 4, ms1); prevS1 = ms1; }
    if (chChanged || abs((int)ms2 - (int)prevS2) > 1) { bleMidiSendCC(ch, 5, ms2); prevS2 = ms2; }
    prevCh = ch;
  }

  CRGB dimColor = color;
  dimColor.nscale8(50);

  for (int dy = 0; dy < displaySize; dy++) {
    for (int dx = 0; dx < displaySize; dx++) {
      const int px = bx + dx;
      const int py = by + dy;
      if (px >= 0 && px < MATRIX_WIDTH && py >= 0 && py < MATRIX_HEIGHT) {
        const bool isOuter = hasDimRing &&
                             (dx == 0 || dx == displaySize - 1 ||
                              dy == 0 || dy == displaySize - 1);
        leds[xyToIndex(px, py)] = isOuter ? dimColor : color;
      }
    }
  }

  FastLED.show();
}

}  // namespace

void setup() {
  Serial.begin(115200);

  pinMode(JOYSTICK_BUTTON_PIN, INPUT_PULLUP);

  analogReadResolution(12);
  analogSetPinAttenuation(JOYSTICK_X_PIN, ADC_11db);
  analogSetPinAttenuation(JOYSTICK_Y_PIN, ADC_11db);
  analogSetPinAttenuation(POT_PIN,        ADC_11db);
  analogSetPinAttenuation(SLIDER1_PIN,    ADC_11db);
  analogSetPinAttenuation(SLIDER2_PIN,    ADC_11db);

  bleMidiInit();

  FastLED.addLeds<NEOPIXEL, LED_PIN>(leds, LED_COUNT);
  FastLED.setBrightness(BRIGHTNESS);
  FastLED.setMaxPowerInVoltsAndMilliamps(5, 50);  // ~200mA real cap — leaves headroom for BLE radio bursts
  FastLED.clear(true);

  calibrateJoystick();

  Serial.println("ready");
}

void loop() {
  static uint32_t lastFrame = 0;

  updateButton();

  const uint32_t now = millis();
  if (now - lastFrame >= FRAME_INTERVAL_MS) {
    lastFrame = now;
    drawPixelFromJoystick();
  }
}

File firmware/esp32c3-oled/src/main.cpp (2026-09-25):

#include <Arduino.h>
#include <FastLED.h>
#include <U8g2lib.h>
#include <Wire.h>

namespace {

// Matrix size.
constexpr uint8_t  MATRIX_WIDTH  = 8;
constexpr uint8_t  MATRIX_HEIGHT = 8;
constexpr uint16_t LED_COUNT     = MATRIX_WIDTH * MATRIX_HEIGHT;

// OLED — 01space 0.42" SSD1306, 72x40, I2C on GPIO5/GPIO6.
constexpr uint8_t OLED_SDA = 5;
constexpr uint8_t OLED_SCL = 6;
constexpr uint32_t SCREEN_INTERVAL_MS = 2000;

// Pins — ESP32-C3 Egg board.
constexpr uint8_t LED_PIN             = 7;
constexpr uint8_t JOYSTICK_X_PIN     = 0;
constexpr uint8_t JOYSTICK_Y_PIN     = 1;
constexpr uint8_t JOYSTICK_BUTTON_PIN = 8;
constexpr uint8_t POT_PIN            = 2;
constexpr uint8_t SLIDER1_PIN        = 3;
constexpr uint8_t SLIDER2_PIN        = 4;

// LED brightness.
constexpr uint8_t BRIGHTNESS = 40;

// Target ~50 fps.
constexpr uint32_t FRAME_INTERVAL_MS = 20;

// Ignore tiny joystick movement around the center.
constexpr int DEADZONE = 250;

// Minimum stable time before a button press is accepted.
constexpr uint32_t DEBOUNCE_MS = 50;

// Full 12-bit ADC range.
constexpr int ADC_MAX = 4095;

// Symmetric deflection range around center.
// Kept below physical ADC max so full deflection reliably clears the last position bin.
constexpr int AXIS_HALF_RANGE = 1500;

// Strobe frequency range controlled by s2 slider.
constexpr float STROBE_HZ_MIN = 1.0f;
constexpr float STROBE_HZ_MAX = 20.0f;

U8G2_SSD1306_72X40_ER_F_SW_I2C u8g2(U8G2_R2, OLED_SCL, OLED_SDA, U8X8_PIN_NONE);

CRGB leds[LED_COUNT];

int centerX = 2048, centerY = 2048;
int axisMinX = 0, axisMaxX = ADC_MAX;
int axisMinY = 0, axisMaxY = ADC_MAX;

constexpr float EMA_ALPHA     = 0.4f;
constexpr float EMA_ALPHA_POT = 0.8f;
float emaX   = 2048.0f;
float emaY   = 2048.0f;
float emaPot = 2048.0f;
float emaSl1 = 2048.0f;
float emaSl2 = 2048.0f;

bool lastButtonReading = HIGH;
bool stableButtonState = HIGH;
uint32_t lastDebounceTime = 0;

// 0=fade  1=white  2=red  3=green  4=blue  5=strobe white  6=strobe fade  7=off
uint8_t colorMode = 0;
constexpr uint8_t COLOR_MODES = 8;

uint8_t fadeHue = 0;
bool displayWasEnabled = true;
int lastBx = -1, lastBy = -1;
bool currentStrobeOn = false;

uint16_t xyToIndex(uint8_t x, uint8_t y) {
  return static_cast<uint16_t>(y * MATRIX_WIDTH + (MATRIX_WIDTH - 1 - x));
}

// All analog pins on ADC1 — no dummy read needed, just average for noise.
int smoothAnalogRead(uint8_t pin, uint8_t samples = 4) {
  long sum = 0;
  for (uint8_t i = 0; i < samples; i++) sum += analogRead(pin);
  return constrain(static_cast<int>(sum / samples), 0, ADC_MAX);
}

void calibrateJoystick() {
  delay(250);
  long sumX = 0, sumY = 0;
  constexpr uint8_t SAMPLES = 32;
  for (uint8_t i = 0; i < SAMPLES; i++) {
    sumX += analogRead(JOYSTICK_X_PIN);
    sumY += analogRead(JOYSTICK_Y_PIN);
    delay(2);
  }
  centerX = static_cast<int>(sumX / SAMPLES);
  centerY = static_cast<int>(sumY / SAMPLES);
  axisMinX = centerX - AXIS_HALF_RANGE;
  axisMaxX = centerX + AXIS_HALF_RANGE;
  axisMinY = centerY - AXIS_HALF_RANGE;
  axisMaxY = centerY + AXIS_HALF_RANGE;
  emaX = static_cast<float>(centerX);
  emaY = static_cast<float>(centerY);
}

uint8_t joystickToPosition(int rawValue, int centerValue,
                           int axisMin, int axisMax, uint8_t size) {
  const int delta = rawValue - centerValue;
  if (abs(delta) < DEADZONE) return size / 2;
  long position;
  if (delta < 0) {
    position = map(rawValue, centerValue - DEADZONE, axisMin, size / 2 - 1, 0);
  } else {
    position = map(rawValue, centerValue + DEADZONE, axisMax, size / 2, size - 1);
  }
  return static_cast<uint8_t>(constrain(position, 0, size - 1));
}

void updateButton() {
  const bool reading = digitalRead(JOYSTICK_BUTTON_PIN);
  if (reading != lastButtonReading) lastDebounceTime = millis();
  lastButtonReading = reading;
  if ((millis() - lastDebounceTime) > DEBOUNCE_MS) {
    if (reading != stableButtonState) {
      stableButtonState = reading;
      if (stableButtonState == LOW) colorMode = (colorMode + 1) % COLOR_MODES;
    }
  }
}

void drawPixelFromJoystick() {
  if (colorMode == 7) {
    if (displayWasEnabled) { FastLED.clear(true); displayWasEnabled = false; }
    return;
  }
  displayWasEnabled = true;

  const int rawX = smoothAnalogRead(JOYSTICK_X_PIN);
  const int rawY = smoothAnalogRead(JOYSTICK_Y_PIN);
  emaX = EMA_ALPHA * rawX + (1.0f - EMA_ALPHA) * emaX;
  emaY = EMA_ALPHA * rawY + (1.0f - EMA_ALPHA) * emaY;
  const int sX  = static_cast<int>(emaX);
  const int sY  = static_cast<int>(emaY);
  emaPot = EMA_ALPHA_POT * smoothAnalogRead(POT_PIN)    + (1.0f - EMA_ALPHA_POT) * emaPot;
  emaSl1 = EMA_ALPHA_POT * smoothAnalogRead(SLIDER1_PIN) + (1.0f - EMA_ALPHA_POT) * emaSl1;
  emaSl2 = EMA_ALPHA_POT * smoothAnalogRead(SLIDER2_PIN) + (1.0f - EMA_ALPHA_POT) * emaSl2;
  const int pot = static_cast<int>(emaPot);
  const int sl1 = static_cast<int>(emaSl1);
  const int sl2 = static_cast<int>(emaSl2);

  FastLED.setBrightness(map(pot, 0, 4095, 0, 255));
  FastLED.clear();

  const int blockSize = map(sl1, 0, 4095, 8, 1);
  // Odd sizes > 1 show as the next even size with a dimmed outer ring.
  const bool hasDimRing = (blockSize > 1 && blockSize % 2 == 1);
  const int displaySize = hasDimRing ? blockSize + 1 : blockSize;
  const uint8_t sizeX = MATRIX_WIDTH  + displaySize - 1;
  const uint8_t sizeY = MATRIX_HEIGHT + displaySize - 1;
  const uint8_t xPos  = joystickToPosition(sX, centerX, axisMinX, axisMaxX, sizeX);
  const uint8_t yBot  = joystickToPosition(sY, centerY, axisMinY, axisMaxY, sizeY);
  const int bx = (int)xPos - (displaySize - 1);
  const int by = (int)(MATRIX_HEIGHT - yBot) - 1;
  const uint8_t joyX = joystickToPosition(sX, centerX, axisMinX, axisMaxX, 9);
  const uint8_t joyY = joystickToPosition(sY, centerY, axisMinY, axisMaxY, 9);
  lastBx = (int)joyX - 4;
  lastBy = 4 - (int)joyY;

  static float    strobePhase    = 0.0f;
  static uint32_t lastStrobeTime = 0;
  const uint32_t  nowMs          = millis();
  const float     dt             = (lastStrobeTime > 0) ? (nowMs - lastStrobeTime) / 1000.0f
                                                        : FRAME_INTERVAL_MS / 1000.0f;
  lastStrobeTime = nowMs;
  const float strobeHz = STROBE_HZ_MIN + ((4095 - sl2) / 4095.0f) * (STROBE_HZ_MAX - STROBE_HZ_MIN);
  strobePhase += strobeHz * dt;
  if (strobePhase >= 1.0f) strobePhase -= 1.0f;
  const bool strobeOn = strobePhase < 0.5f;
  currentStrobeOn = strobeOn;

  if (colorMode == 0) fadeHue++;
  if (colorMode == 6) fadeHue++;
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
